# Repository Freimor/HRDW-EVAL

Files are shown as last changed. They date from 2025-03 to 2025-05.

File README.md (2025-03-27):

## HRDW-EVAL
Bunch of evaluation boards

Design rules for evaluation board:
- Size and pinheader placement defined by breadboard topology
- Silkscreen standart (Name, short description, date format Q1.25)
- Mask color standart (black for final device, white for student's education, red for sensor boards, blue for microcontroller boards, green for other)
- Excessive testpad using, hooks for oscilloscope
- Special via condition (do not use directly on pads. Every signal line through traces)
- Marked resistor only (Except for hard defined)
- All footprints for hand soldering
- Excessive silkscreen marking
- GIT repo address placement required
- All signals on external layers

На русском

- Разрабатываем под установку на макетную плату (так что бы вставала посередине)
- Стандарт маркировки (Наименование, краткий description, дата в формате Q1.25)
- Стандарт по цветам маски (черный под конечное устройство, белый под обучение студентов, красный под сенсор, синий микроконтроллер, зеленый под все остальное)
- Использовать тестпады, зацепы под осциллограф
- Спец условия по расположению via's (не использовать на падах - на удалении. Любой сигнал - через дорожку)
- Резисторы с маркировкой (кроме жестко детерминированных)
- Все посадочные - под ручную пайку
- Развернутая маркировка по возможности
- Указание репозитория на печатной плате
- Все сигналы - на внешних слоях

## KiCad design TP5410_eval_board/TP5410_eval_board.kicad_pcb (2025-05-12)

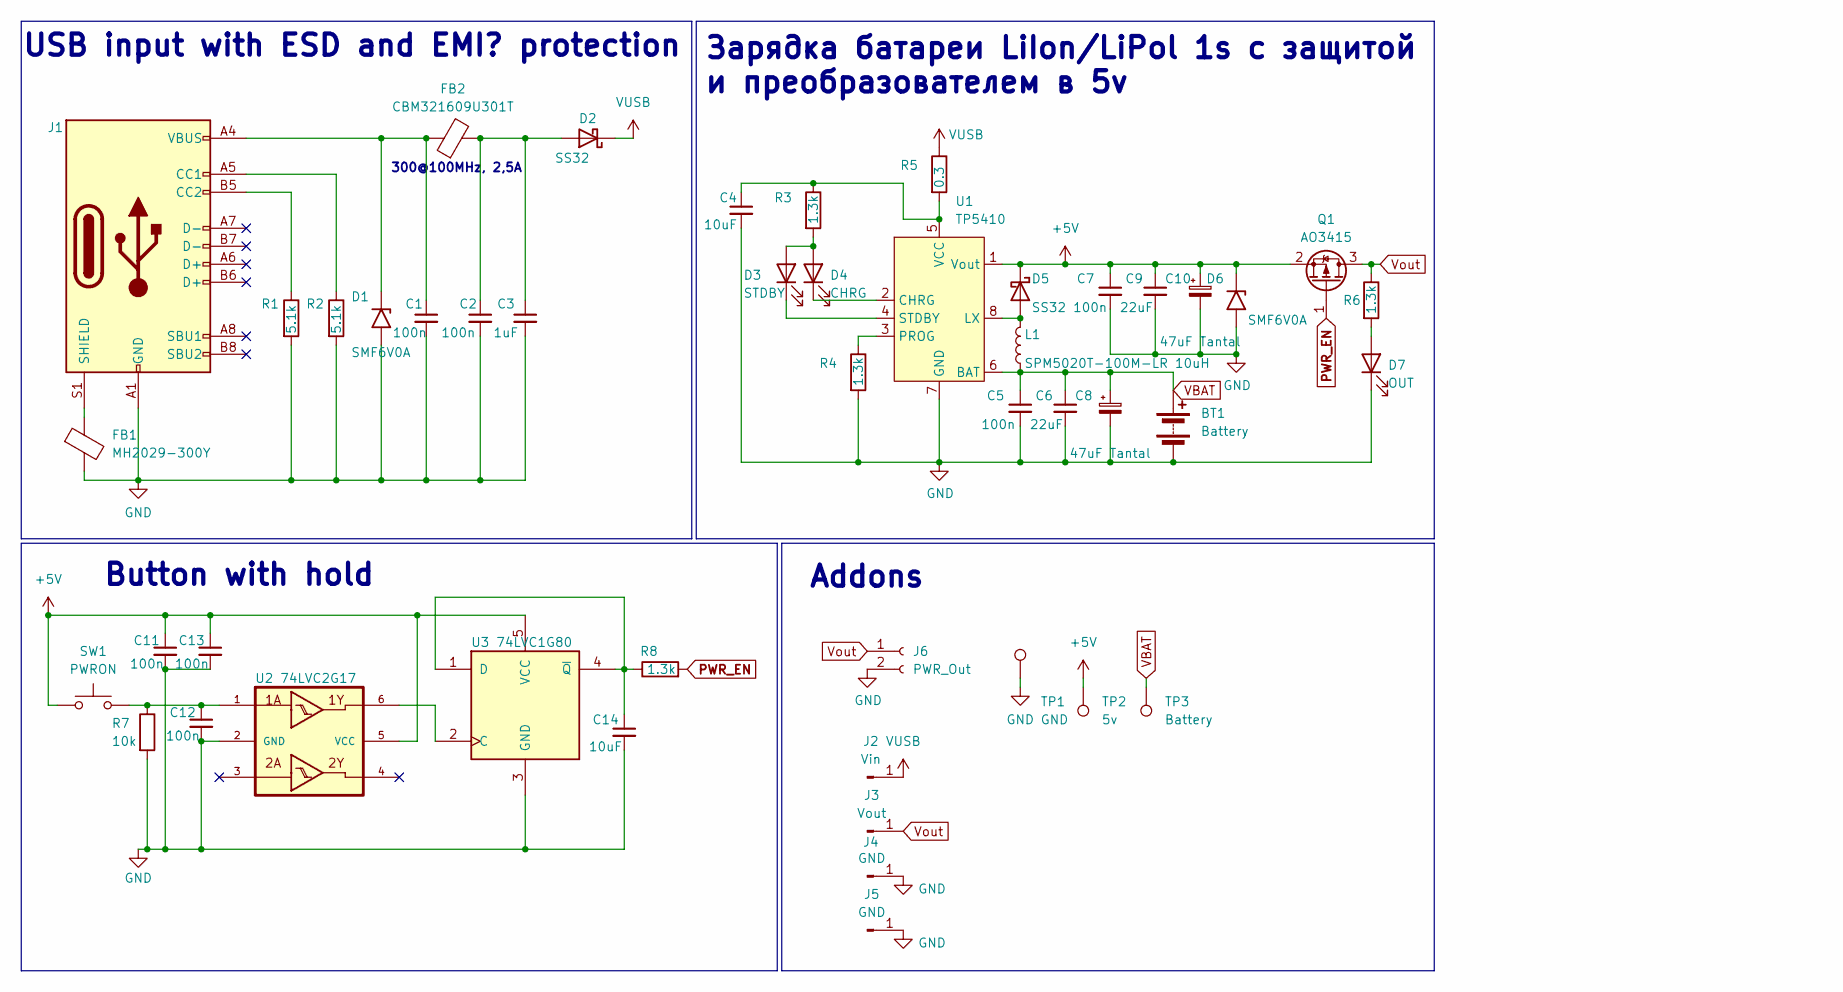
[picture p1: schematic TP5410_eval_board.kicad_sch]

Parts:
BT1: Battery; Conn_XH_JSTlike_2pin_X8821WRS-02-9TSN
C1, C2, C5, C7, C11, C12, C13: 100n; C_0402_1005Metric_Pad0.74x0.62mm_HandSolder
C3: 1uF; C_0603_1608Metric_Pad1.08x0.95mm_HandSolder
C4: 10uF; C_0603_1608Metric_Pad1.08x0.95mm_HandSolder
C6, C9: 22uF; C_0805_2012Metric_Pad1.18x1.45mm_HandSolder
C8, C10: 47uF Tantal; CP_EIA-7343-31_Kemet-D
C14: 10uF; C_0603_1608Metric
D1, D6: SMF6V0A; D_SOD-123F
D2, D5: SS32; D_SMA-SMB_Universal_Handsoldering
D3: STDBY; LED_0603_1608Metric_Pad1.05x0.95mm_HandSolder
D4: CHRG; LED_0603_1608Metric_Pad1.05x0.95mm_HandSolder
D7: OUT; LED_0603_1608Metric_Pad1.05x0.95mm_HandSolder
FB1: MH2029-300Y; L_0805_2012Metric_Pad1.05x1.20mm_HandSolder
FB2: CBM321609U301T; L_1206_3216Metric_Pad1.22x1.90mm_HandSolder
J1: USB_C_Receptacle_USB2.0; RUICHI_TYPE-C-16PF-020
J2: Vin; Castellated_hole_2.54
J3: Vout; Castellated_hole_2.54
J4, J5: GND; Castellated_hole_2.54
J6: PWR_Out; Conn_XH_JSTlike_2pin_X8821WRS-02-9TSN
L1: SPM5020T-100M-LR 10uH; INDUCTOR_SPM5020T
Q1: AO3415; SOT-23
R1, R2: 5.1k; R_0402_1005Metric_Pad0.72x0.64mm_HandSolder
R3, R4, R6, R8: 1.3k; R_0603_1608Metric_Pad0.98x0.95mm_HandSolder
R5: 0.3; R_1210_3225Metric_Pad1.30x2.65mm_HandSolder
R7: 10k; R_0402_1005Metric_Pad0.72x0.64mm_HandSolder
SW1: PWRON; SW_SMD_PAN_EVPAS
TP1: GND; Test_Ring_TH
TP2: 5v; Test_Ring_TH
TP3: Battery; Test_Ring_TH
U1: TP5410
U2: 74LVC2G17; SOT-23-6_Handsoldering
U3: 74LVC1G80

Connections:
+5V: C7.1, C9.1, C10.1, C11.1, C13.1, D5.1 (K), D6.1 (A1), Q1.2 (S), SW1.1, TP2.1, U1.1 (Vout), U2.5 (VCC), U3.5 (VCC)
GND: BT1.2 (-), BT1.S, C1.2, C2.2, C3.2, C4.2, C5.2, C6.2, C7.2, C8.2, C9.2, C10.2, C11.2, C12.2, C13.2, C14.2, D1.2 (A2), D6.2 (A2), D7.1 (K), FB1.2, J1.A1 (GND), J1.A12 (GND), J1.B1 (GND), J1.B12 (GND), J4.1, J5.1, J6.2, J6.S, R1.2, R2.2, R4.2, R7.2, TP1.1, U1.7 (GND), U1.9, U2.2 (GND), U3.3 (GND)
unnamed: C12.1, R7.1, SW1.2, U2.1
unnamed: C1.1, D1.1 (A1), FB2.1, J1.A4 (VBUS), J1.A9 (VBUS), J1.B4 (VBUS), J1.B9 (VBUS)
unnamed: C2.1, C3.1, D2.2 (A), FB2.2
unnamed: D3.2 (A), D4.2 (A), R3.2
unnamed: D3.1 (K), U1.4 (STDBY)
unnamed: D4.1 (K), U1.2 (CHRG)
unnamed: D5.2 (A), L1.2, U1.8 (LX)
unnamed: D7.2 (A), R6.2
unnamed: J1.A5 (CC1), R2.1
unnamed: J1.B5 (CC2), R1.1
unnamed: FB1.1, J1.S1 (SHIELD)
unnamed: R4.1, U1.3 (PROG)
unnamed: C4.1, R3.1, R5.2, U1.5 (VCC)
unnamed: U2.6, U3.2 (C)
unnamed: C14.1, R8.1, U3.1 (D), U3.4 (~Q)
PWR_EN: Q1.1 (G), R8.2
VBAT: BT1.1 (+), C5.1, C6.1, C8.1, L1.1, TP3.1, U1.6 (BAT)
VUSB: D2.1 (K), J2.1, R5.1
Vout: J3.1, J6.1, Q1.3 (D), R6.1

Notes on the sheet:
Зарядка батареи LiIon/LiPol 1s с защитой и преобразователем в 5v
300@100MHz, 2,5A
USB input with ESD and EMI? protection
Button with hold
Addons

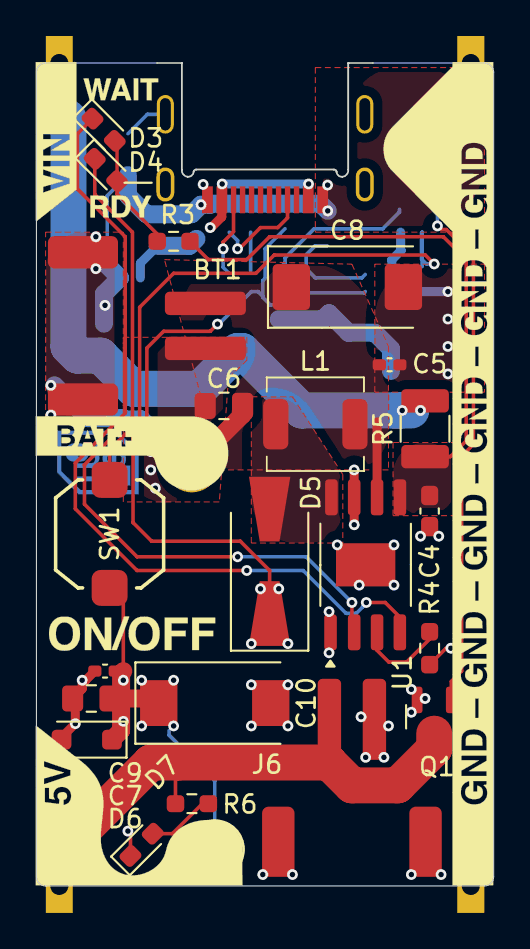
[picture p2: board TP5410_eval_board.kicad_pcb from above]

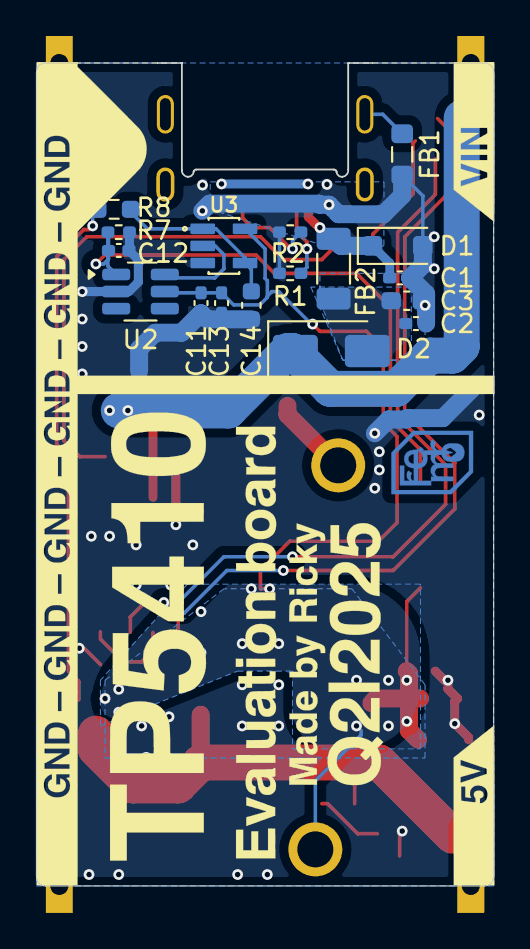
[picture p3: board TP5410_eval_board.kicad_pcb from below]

Board: 2 copper layers, 25.4 x 45.7 mm, 48 parts (17 on the bottom side), 21 nets.

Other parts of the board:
Ref**: Val**; graphic
